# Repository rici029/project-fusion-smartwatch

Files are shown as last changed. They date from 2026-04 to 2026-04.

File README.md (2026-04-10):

# InkTime - Smartwatch Open Source

InkTime este un smartwatch ieftin, open-source, construit in jurul microcontroller-ului **Nordic nRF52840** (BLE 5 + ARM Cortex-M4) si a unui display **e-paper de 1.54"**. Consumul redus al e-paper-ului combinat cu eficienta nRF-ului permite o autonomie de cateva zile pe o baterie LiPo mica.

---

## Cuprins

- [Diagrama bloc](#diagrama-bloc)
- [Descriere hardware](#descriere-hardware)
- [Bill of Materials (BOM)](#bill-of-materials-bom)
- [Pin mapping nRF52840](#pin-mapping-nrf52840)
- [Estimare consum energie](#estimare-consum-energie)
- [Design mecanic](#design-mecanic)
- [Design log](#design-log)
- [Structura repository-ului](#structura-repository-ului)
- [Licenta](#licenta)

---

## Diagrama bloc

Arhitectura dispozitivului se bazeaza pe nRF52840 ca hub central. Acesta comunica cu:

- **Display e-paper** prin SPI + semnale de control (DC/RST/BUSY)
- **Accelerometrul BMA423** prin I2C (pentru detectarea miscarii si step counter)
- **PMIC BQ25180** prin I2C (management incarcare baterie Li-Ion)
- **Driver haptic DRV2605** prin I2C (feedback vibrator)
- **USB-C** pentru incarcare si comunicatie seriala (USB nativ al nRF)
- **3 butoane** pe GPIO-uri dedicate
- **Antena chip 2.4GHz** pentru BLE

Alimentarea este furnizata de un buck-boost **RT6160** care genereaza 3.3V stabil din baterie (domeniu tipic 3.0-4.2V).

---

## Descriere hardware

### Microcontroller - Nordic nRF52840

- **Core:** ARM Cortex-M4F @ 64 MHz
- **Memorie:** 1 MB Flash + 256 KB RAM
- **Radio:** BLE 5.3, 2.4 GHz, puterea TX pana la +8 dBm
- **Interfete:** USB 2.0 Full Speed nativ, SPI, I2C, UART, I2S, PDM, QSPI
- **Justificare alegere:** consum redus (~5 uA in System OFF cu RAM retinuta), suport BLE complet, USB nativ care elimina nevoia de USB-to-Serial

### Power Management

**BQ25180 - Battery Charger (IC1)**
- Incarcator Li-Ion de 1 celula, pana la 550 mA
- Protectii integrate: OVP, SCP, termica
- Control prin I2C - poate raporta starea bateriei si curentul de incarcare
- Pin ALERT (interrupt) catre nRF pentru notificare evenimente

**RT6160 - Buck-Boost DC/DC (IC2)**
- Intrare: 2.5-5.5V (acopera atat VBAT cat si VBUS de la USB)
- Iesire: 3.3V (VREG -> 3V3 rail intern)
- Eficienta >90% la sarcini tipice
- Iesirea VSEL configurabila digital

### Senzori

**BMA423 - Accelerometru 3-axe (IC3)**
- 16-bit, range +/-2/+/-4/+/-8/+/-16 g
- Consum ultra-low: ~3 uA in low-power mode
- Features integrate: step counter, wake-on-tilt, activity recognition
- Comunicatie: I2C
- Doua interrupt-uri (INT1, INT2) pentru wake-up asincron al nRF

### Haptic Feedback

**DRV2605 - Haptic Driver (IC4)**
- Driver pentru motor ERM/LRA (shaker coin motor)
- Librarie integrata de 123 efecte preset
- Control I2C + enable digital (HAPTIC_EN)

### Display

**E-paper 1.54" (model WSH-12561, 200x200 pixel)**
- Conectat prin SPI (MOSI, SCK, EPD_CS) + 3 semnale control (DC, RST, BUSY)
- Circuit de boost integrat - foloseste componentele externe EPD_C1..EPD_C12 (condensatoare + inductor L2, L3 + diode D1-D3 pentru generarea PREVGL/PREVGH/GDR)
- Activare alimentare 3.3V prin MOSFET Q2 controlat de EPD_CS

### USB si protectie

**Conector USB-C (J3)** cu 16 pini (reversibil)
**USBLC6-2SC6Y (D4)** - ESD protection pe liniile D+/D-
Conectare directa la nRF52840 (USB nativ integrat)

### Circuit RF

Antena **2450AT18B100E** (Johanson) cu pi-network de matching:
- **C13, C15, C16** - condensatoare de acord
- **L4 (3.9 nH)** - inductor de matching
- **X1 (32 MHz)** - cristal pentru PLL radio, cu condensatoare de sarcina (12pF)
- **X2 (32.768 kHz)** - cristal pentru RTC (wake-up periodic low-power)

---

## Bill of Materials (BOM)

| Ref | Componenta | Valoare / Model | Capsula | Link JLC Parts | Datasheet |
|-----|---|---|---|---|---|
| IC - nRF | Microcontroller | nRF52840-QIAA | aQFN73 | [JLC](https://jlcpcb.com/parts) | [PDF](https://infocenter.nordicsemi.com/pdf/nRF52840_PS_v1.7.pdf) |
| IC1 | Battery Charger PMIC | BQ25180 | WCSP-8 | [JLC](https://jlcpcb.com/parts) | [PDF](https://www.ti.com/lit/ds/symlink/bq25180.pdf) |
| IC2 | Buck-Boost DC/DC | RT6160A | WQFN-15 | [JLC](https://jlcpcb.com/parts) | [PDF](https://www.richtek.com/assets/product_file/RT6160A/DS6160A-00.pdf) |
| IC3 | Accelerometer | BMA423 | LGA-12 | [JLC](https://jlcpcb.com/parts) | [PDF](https://www.bosch-sensortec.com/media/boschsensortec/downloads/datasheets/bst-bma423-ds000.pdf) |
| IC4 | Haptic Driver | DRV2605 | WCSP-9 | [JLC](https://jlcpcb.com/parts) | [PDF](https://www.ti.com/lit/ds/symlink/drv2605.pdf) |
| U1 | Fuel Gauge | (MAX17048 / LC709203) | WCSP-8 | [JLC](https://jlcpcb.com/parts) | [PDF](https://www.analog.com/media/en/technical-documentation/data-sheets/MAX17048-MAX17049.pdf) |
| ANT1 | Chip Antenna 2.4GHz | 2450AT18B100E | SMD | [JLC](https://jlcpcb.com/parts) | [PDF](https://www.johansontechnology.com/datasheets/2450AT18B100/2450AT18B100.pdf) |
| X1 | Cristal | 32 MHz | 3.2x2.5 mm | [JLC](https://jlcpcb.com/parts) | - |
| X2 | Cristal | 32.768 kHz | 3.2x1.5 mm | [JLC](https://jlcpcb.com/parts) | - |
| L1 | Inductor DC/DC | MLP2016 470nH | 2016 | [JLC](https://jlcpcb.com/parts) | - |
| L2 | Inductor E-paper | 10 uH | 0603 | [JLC](https://jlcpcb.com/parts) | - |
| L3 | Inductor E-paper | 15 uH | 0603 | [JLC](https://jlcpcb.com/parts) | - |
| L4 | Inductor RF matching | 3.9 nH | 0201 | [JLC](https://jlcpcb.com/parts) | - |
| Q2 | MOSFET P-channel | (EPD power switch) | SOT-23 | [JLC](https://jlcpcb.com/parts) | - |
| D1-D3 | Dioda Schottky | (boost converter) | SOD-323 | [JLC](https://jlcpcb.com/parts) | - |
| D4 | ESD USB Protection | USBLC6-2SC6Y | SOT-23-6 | [JLC](https://jlcpcb.com/parts) | [PDF](https://www.st.com/resource/en/datasheet/usblc6-2.pdf) |
| J1 | SWD Programming | TC2030-IDC | THT | [JLC](https://jlcpcb.com/parts) | [PDF](https://www.tag-connect.com/wp-content/uploads/bsk-pdf-manager/TC2030-IDC_Datasheet_14.pdf) |
| J2 | FPC Connector | 503480-2400 (24p) | SMD | [JLC](https://jlcpcb.com/parts) | [PDF](https://www.molex.com/pdm_docs/sd/5034802400_sd.pdf) |
| J3 | USB-C | KH-TYPE-C-16P | SMD | [JLC](https://jlcpcb.com/parts) | - |
| SW1-3 | Buton tactil | SMD side-push | SMD | [JLC](https://jlcpcb.com/parts) | - |
| Baterie | LiPo 3.7V | AKY0106 | - | - | [PDF](https://www.tme.eu/Document/b9e12bf26ad0ba929a22ab5d58f022cd/AKY0106.pdf) |
| Display | E-paper 1.54" | WSH-12561 | FPC | - | [PDF](https://www.tme.eu/Document/0ca57a8ffbcd57b5bca53252eb9d6ec3/WSH-12561.pdf) |
| Shaker | Motor vibrator | DFRobot FIT0774 | coin | - | [link](https://www.tme.eu/ro/details/df-fit0774/motoare-dc/dfrobot/fit0774/) |

**Condensatoare si rezistente:** toate in capsule 0201 (pentru valori <= 100 nF) sau 0402 (pentru valori > 100 nF), conform cerintei proiectului. Vezi fisierul `Manufacturing/bom.txt` pentru lista completa cu referinte si valori.

---

## Pin mapping nRF52840

| Pin nRF52840 | Net / Semnal | Functie | Motivatie alegere |
|---|---|---|---|
| P0.26 | SCL | I2C Clock | Pin GPIO standard, aproape de IC-urile I2C (BMA423, BQ25180, DRV2605) pentru trase scurte |
| P0.27 | SDA | I2C Data | Pereche cu P0.26 pentru TWI0 |
| P0.04 | IMU_INT1 | Interrupt BMA423 | Pin cu capabilitate AIN (ADC) dar folosit ca GPIO - pozitie convenabila pe PCB |
| P0.13 | SCK | SPI Clock (E-paper) | High-speed GPIO, suport SPIM |
| P0.14 | MOSI | SPI Data (E-paper) | Pereche cu SCK pe aceeasi periferica SPIM |
| P0.19 | EPD_CS | Chip Select e-paper | GPIO simplu, control SPI CS |
| P0.20 | EPD_DC | Data/Command | Control semnal pentru display |
| P0.21 | EPD_RST | Reset e-paper | GPIO cu output drive standard |
| P0.22 | EPD_BUSY | Busy signal | Input de la display, pentru polling |
| P0.23 | HAPTIC_EN | Enable DRV2605 | GPIO simplu, activeaza driver-ul haptic |
| P0.24 | PMIC_INT | Interrupt BQ25180 | Interrupt la evenimente de charging |
| P0.25 | ALERT | Alert fuel gauge | Notificare low-battery |
| P0.09, P0.10 | SW1, SW2 (Buttons) | Butoane utilizator | Pini dedicati cu suport NFC dezactivat (configurabili GPIO) |
| P1.09 | SW3 | Al treilea buton | GPIO free pe portul P1 |
| P1.01 | IMU_INT2 | Interrupt secundar BMA423 | GPIO free |
| SWDIO, SWDCLK | TP + J1 | Programming / Debug | Pini dedicati SWD, accesibili prin TC2030 si test pad-uri |
| XL1, XL2 | X2 (32.768 kHz) | LFCLK pentru RTC | Pini dedicati oscilatorului low-frequency |
| XC1, XC2 | X1 (32 MHz) | HFCLK pentru radio | Pini dedicati oscilatorului high-frequency |
| D+/D- | USB | USB native | Pini dedicati, conectati direct la USB-C prin USBLC6 |
| ANT | ANT1 | Antena BLE | Pin RF dedicat, conectat prin reteaua de matching |

**Nota:** Pinii ADC (P0.02-P0.05, P0.28-P0.31) care nu sunt folositi ca AIN sunt disponibili pentru extensii viitoare (ex: senzori analogici aditionali).

---

## Estimare consum energie

| Mod de operare | Componente active | Consum estimat |
|---|---|---|
| Sleep (System OFF + RAM) | nRF RAM retained + RTC + BMA423 low-power | **~10 uA** |
| Idle (display static, BLE advertising) | nRF BLE adv + RTC + IMU | **~50 uA** |
| Active (refresh display) | nRF MCU on + SPI + EPD boost | ~8 mA (~500 ms per refresh) |
| BLE connected (data transfer) | nRF radio TX/RX @ 0 dBm | ~5-8 mA |
| Charging | BQ25180 la 500 mA | de la USB, nu de la baterie |

**Autonomie estimata:**  
Baterie tipica: ~110 mAh (AKY0106).  
Cu consum mediu ~50 uA (majoritatea timpului in idle + cateva refresh-uri de display pe ora):

T_autonomie = 110 mAh / 0.05 mA = 2200 ore ~ 90 zile

In practica, cu uzura normala (notificari, interactiuni cu butoanele, sync BLE), **durata de viata realista pe baterie este de ~2-4 saptamani**.

---

## Design mecanic

Dispozitivul este construit din:
- **PCB 1 mm grosime**, 4 layere (Top + 2 Inner GND + Bottom)
- **Carcasa** cu TopCase (rama + fereastra display) + BottomCase (compartiment baterie)
- **Baterie LiPo** plasata sub PCB in compartimentul BottomCase
- **Display e-paper** montat deasupra PCB, aliniat cu fereastra TopCase
- **Shaker motor** plasat lateral, conectat la PCB prin pad-uri TP_OUT+/OUT-
- **3 butoane fizice** aliniate cu SW1-SW3 pe PCB

Bateria se conecteaza direct la 2 test pad-uri (TP_BAT / TP_GND) in loc sa foloseasca conectorul JST original, pentru a economisi spatiu.

---

## Design log

### Decizii importante luate

1. **Alegerea stack-up-ului 4 layere:** desi un design 2-layer ar fi fost posibil, am optat pentru 4 layere cu doua planuri GND interne (Optiunea B). Motivele:
   - Return path continuu pentru semnalele SPI (display) si USB D+/D-
   - Performanta RF mai buna pentru circuitul BLE 2.4 GHz
   - Simplificare rutare - nu mai trebuie evitate via-urile pe trasee de putere
   - Ecranare EMI imbunatatita intre TOP si BOTTOM

2. **Rutarea 3V3 ca trasee groase (nu plane):** pentru ca 3V3 e consumator redus (< 100 mA) am preferat trasee groase (0.3 mm) pe TOP/BOTTOM in loc de un plane intern. Inner layers raman ambele GND.

3. **Antena la marginea PCB-ului + decupare:** am plasat antena 2450AT18B100E la marginea placii, cu zona de sub ea **decupata mecanic** si fara cupru pe niciun layer (conform datasheet si cerintei). In jurul antenei am adaugat via stitching pentru a lega planurile GND.

4. **Keepout pe toate cele 4 layere sub antena:** am desenat dreptunghiuri pe tRestrict, bRestrict si echivalentele pentru inner layers, plus decupare pe Dimension/Milling.

5. **Via stitching in zona RF:** plasate via-uri GND (0.3 mm drill / 0.6 mm diametru) la ~1.5 mm distanta in jurul nRF52840 si antenei pentru continuitate planuri GND.

6. **Plasarea condensatoarelor de decuplare:** toate cele 100 nF sunt plasate in capsula 0201 direct langa pinii VDD ai nRF, BMA423, DRV2605, BQ25180 si RT6160.

### Probleme intampinate

- **Rutare sub BGA nRF52840:** pinii interni ai BGA-ului au spatiere foarte mica; traseele de intrare/iesire din zona BGA au fost ingustate la 0.127 mm pentru a se incadra intre bile. Au aparut erori DRC "width too small" dar sunt acceptate conform cerintei.
- **Spatiu limitat pentru rutare:** placa de smartwatch fiind compacta (~35x40 mm), am trecut la 4 layere pentru a avea suficient spatiu de rutare.
- **Orientarea FPC-ului display-ului:** conectorul J2 a fost orientat astfel incat cablul flat sa aiba lungime minima pana la display, fara bucle.
- **Net classes aplicate dupa ce am inceput rutarea:** am adaugat clasa "Power" cu width 0.3 mm dupa ce rutasem deja cateva trasee la 0.15 mm. Am folosit comanda CHANGE WIDTH pentru a le ingrosa.

---

## Structura repository-ului

```
InkTime/
├── Hardware/
│   ├── InkTime_Schematic.sch     # Schematicul Fusion
│   ├── InkTime_Schematic.brd     # Board-ul Fusion
│   └── InkTime_Schematic.pdf     # Print-out schematic
├── Manufacturing/
│   ├── gerbers.zip               # Fisiere Gerber + Drill
│   ├── bom.txt                   # Bill of Materials
│   └── cpl.txt                   # Pick and Place
├── Mechanical/
│   ├── complete_device.step      # Model 3D exploded
│   └── complete_device.f3z       # Fisier Fusion Design complet
├── Images/
│   ├── block_diagram.png
│   ├── pcb_top.png
│   ├── pcb_bottom.png
│   ├── pcb_3d_top.png
│   └── device_3d.png
├── LICENSE                       # Apache 2.0
└── README.md
```

---

## Licenta

Acest proiect este licentiat sub **Apache License 2.0**. Vezi fisierul [LICENSE](LICENSE) pentru detalii.

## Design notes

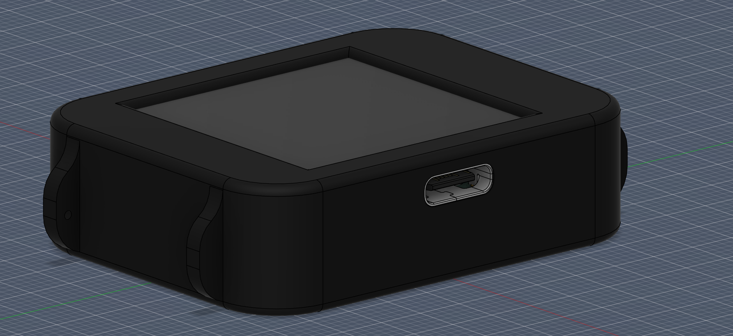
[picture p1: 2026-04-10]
device_3d.png

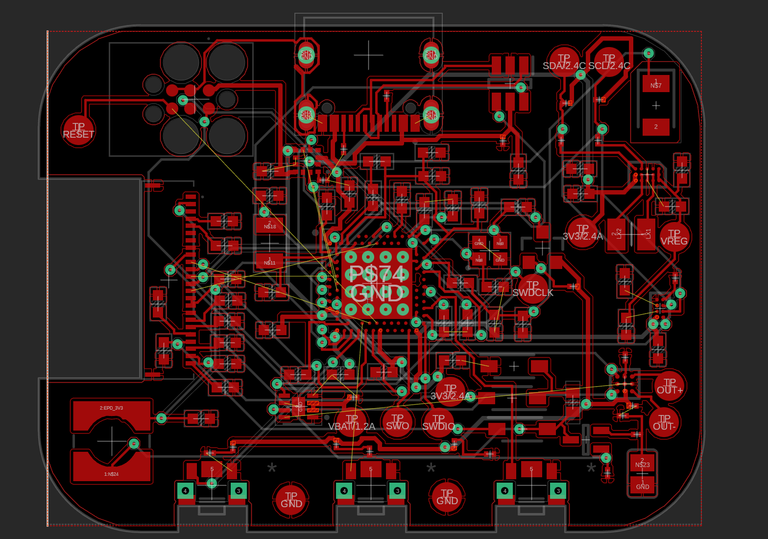
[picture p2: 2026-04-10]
pcb_top.png

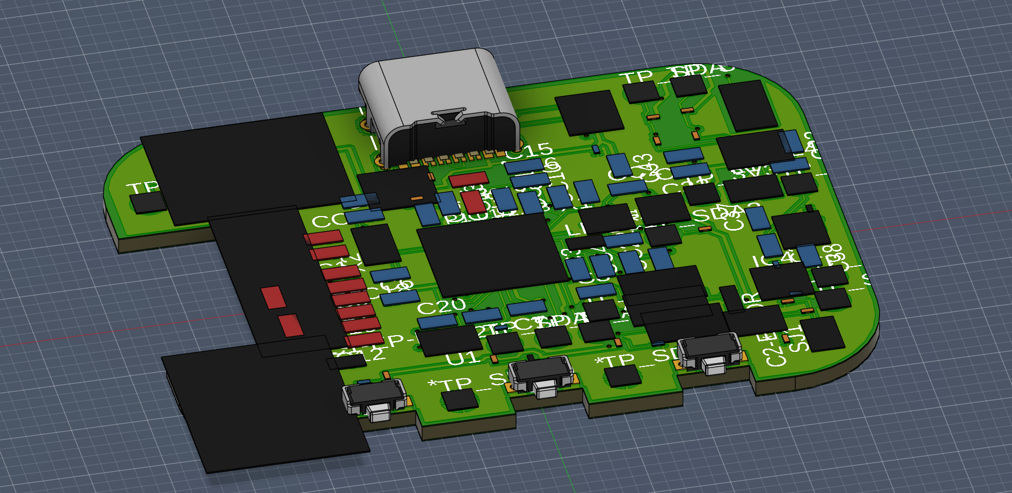
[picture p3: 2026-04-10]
pcb_3d.png

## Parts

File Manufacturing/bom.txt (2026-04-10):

Partlist exported from Fusion Hub: bogdanpanaitiu   Project: Default Project  Board: InkTime_Schematic at 19/04/2026 16:12

Qty Value                                                   Device                                                                       Package                                                                                                                Parts                                                                                                                      Description                                                                                                               ARROW_PART_NUMBER ARROW_PRICE-STOCK                                                                                AVAILABILITY CHECK_PRICES                                                                       COPYRIGHT                                                DESCRIPTION                                                                                              DIGI-KEY_PART_NUMBER_1                    DIGI-KEY_PART_NUMBER_2 DIGI-KEY_PART_NUMBER_3                              HEIGHT  JLCPCB MANUFACTURER_NAME   MANUFACTURER_PART_NUMBER                                         MF                 MFR_NAME          MOUSER_PART_NUMBER MOUSER_PRICE-STOCK                                                                                           MP                                                                                                       PACKAGE                     POPULARITY PRICE            PROD_ID                      PURCHASE-URL                                                                                                                               SNAPEDA_LINK                                                                      SPICEMODEL SPICEPREFIX                                                                                                                                     TP_SIGNAL_NAME                                                                      VALUE             
1   0                                                       ESP32_C6_LIBRARY_7_JUMPER_SJ                                                 ESP32_C6_LIBRARY_7_JUMPER_SJ                                                                                           SJ1                                                                                                                        SMD solder JUMPER                                                                                                                                                                                                                                                                                                                                                                                                                                                                                                                                                                                                                                                                                                                                                                                                                                                                                                                                                                                                                                 3                                                                                                                                                                                                                                                                                                                                                                                                                                                                                                                                                      
1   0.1uF                                                   GRM011R60J152KE01L_1_GRM011R60J152KE01L                                      GRM011R60J152KE01L_1_0201                                                                                              C4                                                                                                                         Check availability                                                                                                                                                                                                                                                                                                                                                                                                                                                                                                                                                                                                                                                                                                                                                                                                                                                                                                                                                                                                                                                                                                                                                                                                                                                                                                                                                                                                                                                                                                                                                                                       
1   0.1uF                                                   NORDIC_NRF_3_CAPACITOR_0402_M                                                NORDIC_NRF_3_RESC0402_M                                                                                                C23                                                                                                                        Generic chip capacitor                                                                                                                                                                                                                                                                                                                                                                                                                                                                                                                                                                                                                                                                                                                                                                                                                                                                                                                                                                                                                                                                                                                                                                                                                                                                                                                                                                                                                                                                                                                                                                                   
1   0.1uF/50V                                               NORDIC_NRF_3_CAPACITOR_0402_M                                                NORDIC_NRF_3_RESC0402_M                                                                                                EPD_C5                                                                                                                     Generic chip capacitor                                                                                                                                                                                                                                                                                                                                                                                                                                                                                                                                                                                                                                                                                                                                                                                                                                                                                                                                                                                                                                                                                                                                                                                                                                                                                                                                                                                                                                                                                                                                                                                   
4   100nF                                                   NORDIC_NRF_3_CAPACITOR_0402_M                                                NORDIC_NRF_3_RESC0402_M                                                                                                C7, C8, CC5, CC19                                                                                                          Generic chip capacitor                                                                                                                                                                                                                                                                                                                                                                                                                                                                                                                                                                                                                                                                                                                                                                                                                                                                                                                                                                                                                                                                                                                                                                                                                                                                                                                                                                                                                                                                                                                                                                                   
2   100pF                                                   NORDIC_NRF_3_CAPACITOR_0402_M                                                NORDIC_NRF_3_RESC0402_M                                                                                                C12, CC11                                                                                                                  Generic chip capacitor                                                                                                                                                                                                                                                                                                                                                                                                                                                                                                                                                                                                                                                                                                                                                                                                                                                                                                                                                                                                                                                                                                                                                                                                                                                                                                                                                                                                                                                                                                                                                                                   
1   10K                                                     CPF0201D7K68C1_CPF0201D7K68C1                                                CPF0201D7K68C1_0201                                                                                                    R1                                                                                                                         7.68k 0201 Thin Film Surface Mount Fixed Resistor +/-0.5% 0.031W CPF0201D7K68C1                                                                                                                                                                                                                                                                                                                                                                                                                                                                                                                                                                                                                                                                                                                                                                                                                                                                                                                                                                                                                                                                                                                                                                                                                                                                                                                                                                                                                                                                                                                          
3   10uF                                                    NORDIC_NRF_3_CAPACITOR_0402_M                                                NORDIC_NRF_3_RESC0402_M                                                                                                C1-EP-DR, C24, C39                                                                                                         Generic chip capacitor                                                                                                                                                                                                                                                                                                                                                                                                                                                                                                                                                                                                                                                                                                                                                                                                                                                                                                                                                                                                                                                                                                                                                                                                                                                                                                                                                                                                                                                                                                                                                                                   
1   10uH                                                    NORDIC_NRF_2_INDUCTOR_0402_M                                                 NORDIC_NRF_2_RESC0402_M                                                                                                LL2                                                                                                                        Generic chip inductor                                                                                                                                                                                                                                                                                                                                                                                                                                                                                                                                                                                                                                                                                                                                                                                                                                                                                                                                                                                                                                                                                                                                                                                                                                                                                                                                                                                                                                                                                                                                                                                    
4   12pF                                                    NORDIC_NRF_3_CAPACITOR_0402_M                                                NORDIC_NRF_3_RESC0402_M                                                                                                C17, C18, CC1, CC2                                                                                                         Generic chip capacitor                                                                                                                                                                                                                                                                                                                                                                                                                                                                                                                                                                                                                                                                                                                                                                                                                                                                                                                                                                                                                                                                                                                                                                                                                                                                                                                                                                                                                                                                                                                                                                                   
1   15uH                                                    NORDIC_NRF_2_INDUCTOR_0402_M                                                 NORDIC_NRF_2_RESC0402_M                                                                                                LL3                                                                                                                        Generic chip inductor                                                                                                                                                                                                                                                                                                                                                                                                                                                                                                                                                                                                                                                                                                                                                                                                                                                                                                                                                                                                                                                                                                                                                                                                                                                                                                                                                                                                                                                                                                                                                                                    
2   1pF                                                     NORDIC_NRF_3_CAPACITOR_0402_M                                                NORDIC_NRF_3_RESC0402_M                                                                                                CC3, CC4                                                                                                                   Generic chip capacitor                                                                                                                                                                                                                                                                                                                                                                                                                                                                                                                                                                                                                                                                                                                                                                                                                                                                                                                                                                                                                                                                                                                                                                                                                                                                                                                                                                                                                                                                                                                                                                                   
1   1uF                                                     GRM011R60J152KE01L_1_GRM011R60J152KE01L                                      GRM011R60J152KE01L_1_0201                                                                                              C3                                                                                                                         Check availability                                                                                                                                                                                                                                                                                                                                                                                                                                                                                                                                                                                                                                                                                                                                                                                                                                                                                                                                                                                                                                                                                                                                                                                                                                                                                                                                                                                                                                                                                                                                                                                       
3   1uF                                                     NORDIC_NRF_3_CAPACITOR_0402_M                                                NORDIC_NRF_3_RESC0402_M                                                                                                C15, C37, C38                                                                                                              Generic chip capacitor
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

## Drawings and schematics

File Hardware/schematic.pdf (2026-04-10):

A

A

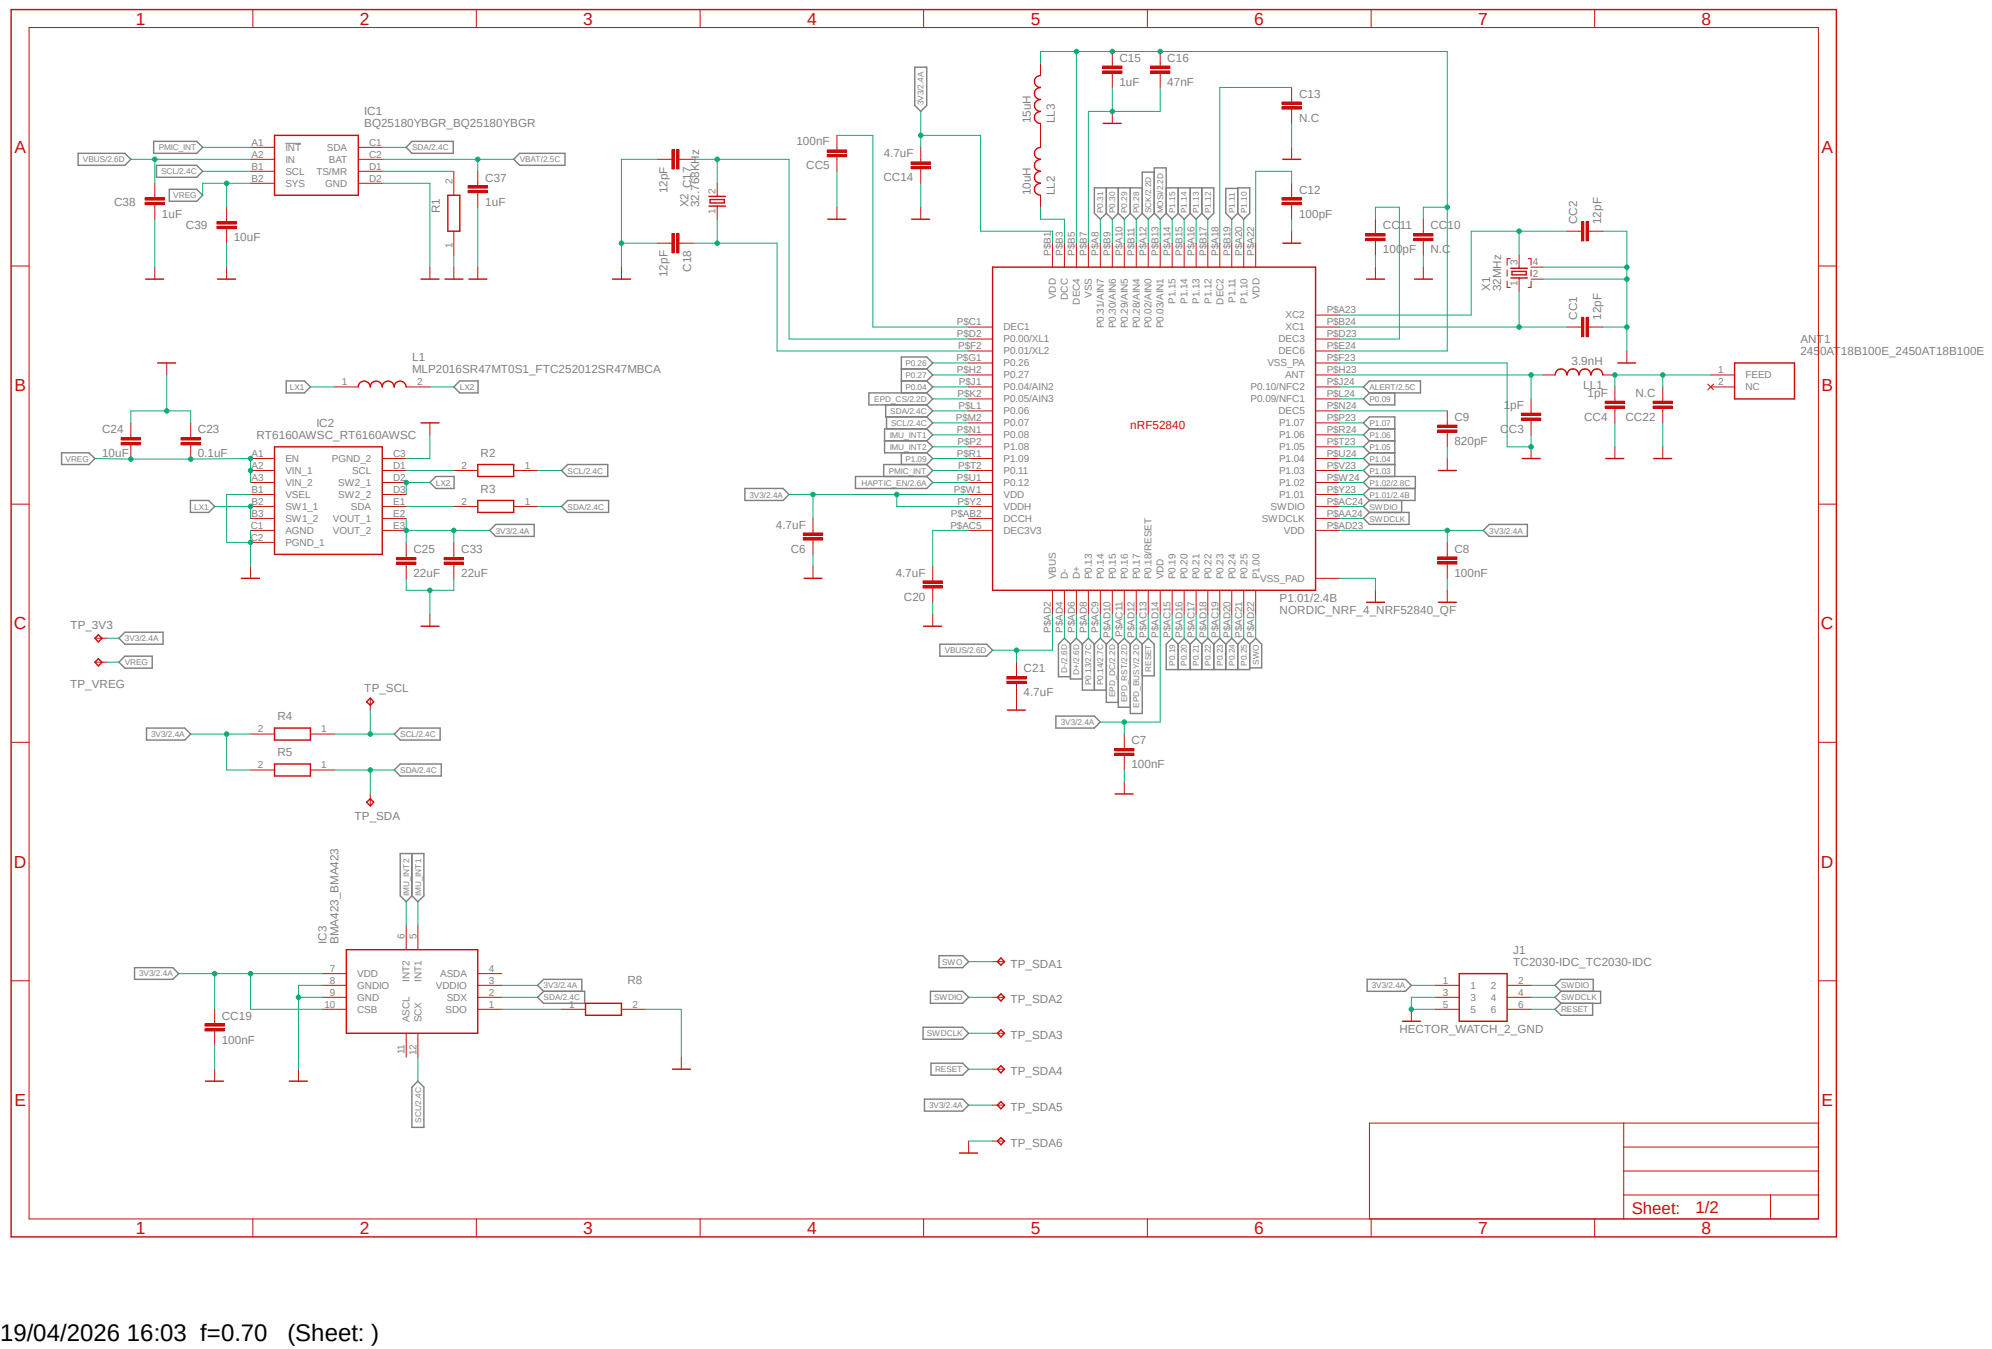
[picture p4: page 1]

P0.07 P$M2 | P1.07
P0.08 P$N1 | P1.06
P1.08 P$P2 | P1.05

19/04/2026 16:03 f=0.70 (Sheet: ) EPD_3V³ | EPD_3V³

# EPD_3V3 GDR

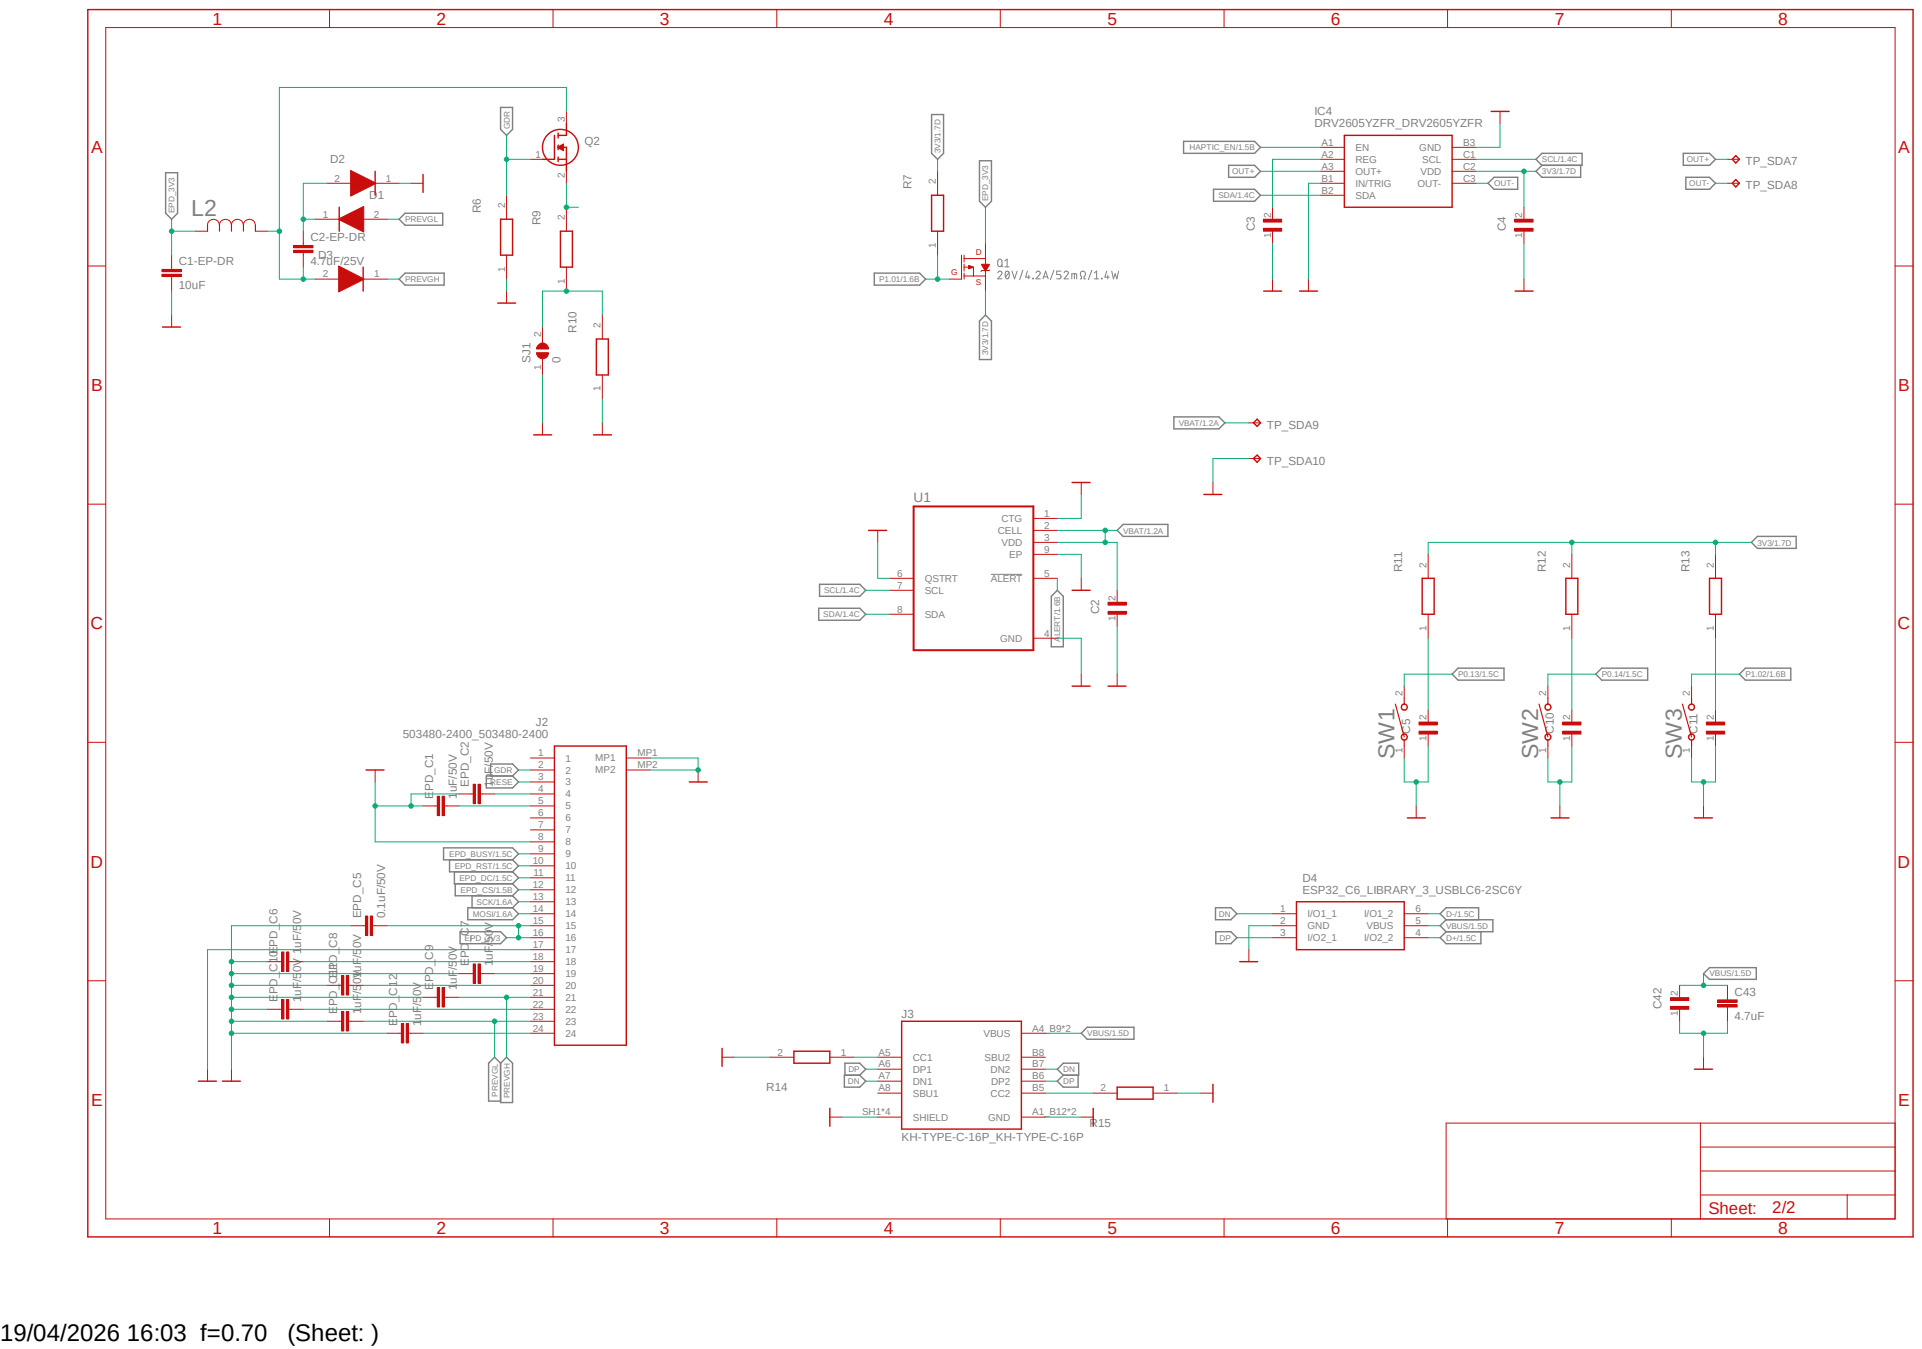
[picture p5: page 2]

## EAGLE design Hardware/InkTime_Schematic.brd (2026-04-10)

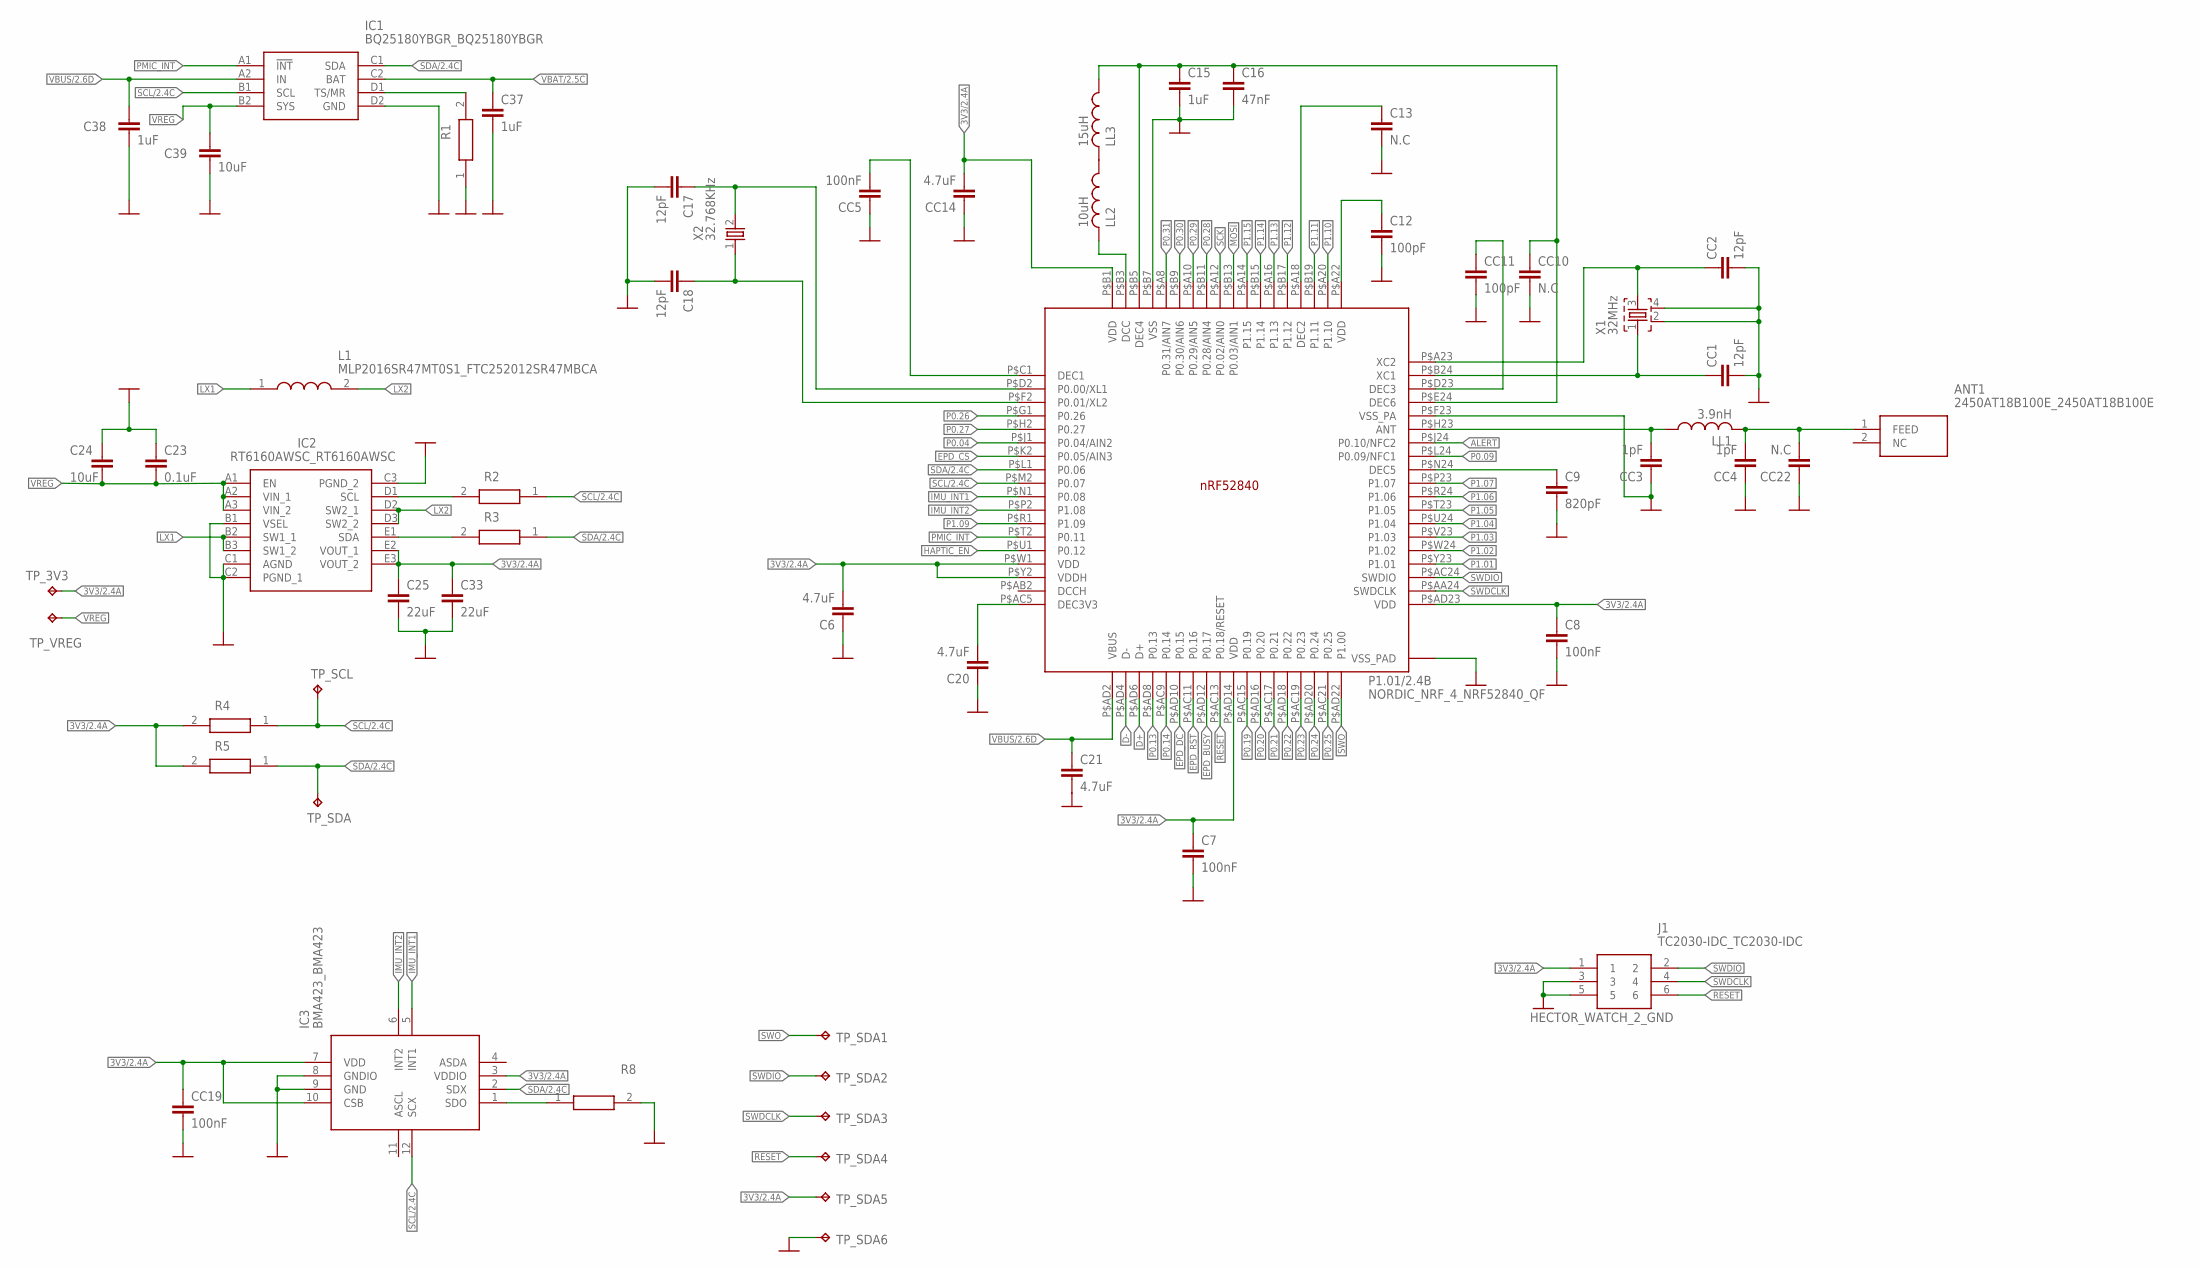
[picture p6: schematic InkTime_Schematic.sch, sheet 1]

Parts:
ANT1: 2450AT18B100E_2450AT18B100E; 2450AT18B100E_ANTC3216X140N
C6, C20, C21: 4.7uF; NORDIC_NRF_3_RESC0402_M
C7, C8: 100nF; NORDIC_NRF_3_RESC0402_M
C9: 820pF; NORDIC_NRF_3_RESC0402_M
C12: 100pF; NORDIC_NRF_3_RESC0402_M
C13: N.C; NORDIC_NRF_3_RESC0402_M
C15, C37, C38: 1uF; NORDIC_NRF_3_RESC0402_M
C16: 47nF; NORDIC_NRF_3_RESC0402_M
C17, C18: 12pF; NORDIC_NRF_3_RESC0402_M
C23: 0.1uF; NORDIC_NRF_3_RESC0402_M
C24, C39: 10uF; NORDIC_NRF_3_RESC0402_M
C25, C33: 22uF; NORDIC_NRF_3_RESC0402_M
CC1, CC2: 12pF; NORDIC_NRF_3_RESC0402_M
CC3, CC4: 1pF; NORDIC_NRF_3_RESC0402_M
CC5, CC19: 100nF; NORDIC_NRF_3_RESC0402_M
CC10, CC22: N.C; NORDIC_NRF_3_RESC0402_M
CC11: 100pF; NORDIC_NRF_3_RESC0402_M
CC14: 4.7uF; NORDIC_NRF_3_RESC0402_M
IC1: BQ25180YBGR_BQ25180YBGR; BQ25180YBGR_BGA8C40P2X4_100X155X50
IC2: RT6160AWSC_RT6160AWSC; RT6160AWSC_BGA15C40P3X5_140X230X60
IC3: BMA423_BMA423
J1: TC2030-IDC_TC2030-IDC; TC2030-IDC_TC2030IDC
L1: MLP2016SR47MT0S1_FTC252012SR47MBCA; MLP2016SR47MT0S1_INDC2016X100N
LL1: 3.9nH; NORDIC_NRF_2_RESC0402_M
LL2: 10uH; NORDIC_NRF_2_RESC0402_M
LL3: 15uH; NORDIC_NRF_2_RESC0402_M
P1.01/2.4B: NORDIC_NRF_4_NRF52840_QF; NORDIC_NRF_4_AQFN50P700X700X85_HS-74N
R1: 10K; CPF0201D7K68C1_0201
R2, R3, R4, R5, R8: CPF0201D7K68C1_CPF0201D7K68C1; CPF0201D7K68C1_0201
TP_3V3: HECTOR_WATCH_1_TPTP20R; HECTOR_WATCH_1_TP20R
TP_SCL: HECTOR_WATCH_1_TPTP20R; HECTOR_WATCH_1_TP20R
TP_SDA, TP_SDA1, TP_SDA2, TP_SDA3, TP_SDA4, TP_SDA5, TP_SDA6: HECTOR_WATCH_1_TPTP20R; HECTOR_WATCH_1_TP20R
TP_VREG: HECTOR_WATCH_1_TPTP20R; HECTOR_WATCH_1_TP20R
X1: 32MHz; NORDIC_NRF_BT-XTAL_2016_N
X2: 32.768KHz; NORDIC_NRF_1_XTAL_3215_N

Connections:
3V3/2.4A: C6.2, C7.1, C8.1, C25.1, C33.1, CC14.2, CC19.1, IC2.E2 (VOUT_1), IC2.E3 (VOUT_2), IC3.3 (VDDIO), IC3.7 (VDD), IC3.10 (CSB), J1.1, P1.01/2.4B.P$AD14 (VDD), P1.01/2.4B.P$AD23 (VDD), P1.01/2.4B.P$B1 (VDD), P1.01/2.4B.P$W1 (VDD), P1.01/2.4B.P$Y2 (VDDH), R4.2, R5.2, TP_3V3.TP, TP_SDA5.TP
ALERT: P1.01/2.4B.P$J24 (P0.10/NFC2); also elsewhere on the board
D+: P1.01/2.4B.P$AD6 (D+); also elsewhere on the board
D-: P1.01/2.4B.P$AD4 (D-); also elsewhere on the board
EPD_BUSY: P1.01/2.4B.P$AD12 (P0.17); also elsewhere on the board
EPD_CS: P1.01/2.4B.P$K2 (P0.05/AIN3); also elsewhere on the board
EPD_DC: P1.01/2.4B.P$AD10 (P0.15); also elsewhere on the board
EPD_RST: P1.01/2.4B.P$AC11 (P0.16); also elsewhere on the board
GND: C6.1, C7.2, C8.2, C9.2, C12.2, C13.2, C15.2, C16.2, C17.2, C18.2, C20.1, C21.2, C23.1, C24.1, C25.2, C33.2, C37.2, C38.2, C39.2, CC1.2, CC2.2, CC3.1, CC4.1, CC5.1, CC10.2, CC11.2, CC14.1, CC19.2, CC22.1, IC1.D2 (GND), IC2.B1 (VSEL), IC2.C1 (AGND), IC2.C2 (PGND_1), IC2.C3 (PGND_2), IC3.8 (GNDIO), IC3.9 (GND), J1.3, J1.5, P1.01/2.4B.P$74 (VSS_PAD), P1.01/2.4B.P$75 (VSS_PAD), P1.01/2.4B.P$76 (VSS_PAD), P1.01/2.4B.P$77 (VSS_PAD), P1.01/2.4B.P$78 (VSS_PAD), P1.01/2.4B.P$79 (VSS_PAD), P1.01/2.4B.P$80 (VSS_PAD), P1.01/2.4B.P$81 (VSS_PAD), P1.01/2.4B.P$82 (VSS_PAD), P1.01/2.4B.P$83 (VSS_PAD), P1.01/2.4B.P$84 (VSS_PAD), P1.01/2.4B.P$85 (VSS_PAD), P1.01/2.4B.P$86 (VSS_PAD), P1.01/2.4B.P$87 (VSS_PAD), P1.01/2.4B.P$88 (VSS_PAD), P1.01/2.4B.P$89 (VSS_PAD), P1.01/2.4B.P$90 (VSS_PAD), P1.01/2.4B.P$B7 (VSS), P1.01/2.4B.P$F23 (VSS_PA), R1.1, R8.2, TP_SDA6.TP, X1.2, X1.4; also elsewhere on the board
HAPTIC_EN: P1.01/2.4B.P$U1 (P0.12); also elsewhere on the board
IMU_INT1: IC3.5 (INT1), P1.01/2.4B.P$N1 (P0.08)
IMU_INT2: IC3.6 (INT2), P1.01/2.4B.P$P2 (P1.08)
LX1: IC2.B2 (SW1_1), IC2.B3 (SW1_2), L1.1
LX2: IC2.D2 (SW2_1), IC2.D3 (SW2_2), L1.2
MOSI: P1.01/2.4B.P$B13 (P0.03/AIN1); also elsewhere on the board
unnamed: IC1.D1 (TS/MR), R1.2
unnamed: C9.1, P1.01/2.4B.P$N24 (DEC5)
unnamed: CC3.2, LL1.1, P1.01/2.4B.P$H23 (ANT)
unnamed: IC2.D1 (SCL), R2.2
unnamed: IC2.E1 (SDA), R3.2
unnamed: C20.2, P1.01/2.4B.P$AC5 (DEC3V3)
unnamed: ANT1.1 (FEED), CC4.2, CC22.2, LL1.2
unnamed: CC1.1, P1.01/2.4B.P$B24 (XC1), X1.1
unnamed: CC2.1, P1.01/2.4B.P$A23 (XC2), X1.3
unnamed: CC11.1, P1.01/2.4B.P$D23 (DEC3)
unnamed: C18.1, P1.01/2.4B.P$F2 (P0.01/XL2), X2.1
unnamed: C12.1, P1.01/2.4B.P$A22 (VDD)
unnamed: C13.1, P1.01/2.4B.P$A18 (DEC2)
unnamed: LL2.1, LL3.2
unnamed: LL2.2, P1.01/2.4B.P$B3 (DCC)
unnamed: C15.1, C16.1, CC10.1, LL3.1, P1.01/2.4B.P$B5 (DEC4), P1.01/2.4B.P$E24 (DEC6)
unnamed: C17.1, P1.01/2.4B.P$D2 (P0.00/XL1), X2.2
unnamed: IC3.1 (SDO), R8.1
unnamed: CC5.2, P1.01/2.4B.P$C1 (DEC1)
P0.04: P1.01/2.4B.P$J1 (P0.04/AIN2)
P0.09: P1.01/2.4B.P$L24 (P0.09/NFC1)
P0.13: P1.01/2.4B.P$AD8 (P0.13); also elsewhere on the board
P0.14: P1.01/2.4B.P$AC9 (P0.14); also elsewhere on the board
P0.19: P1.01/2.4B.P$AC15 (P0.19)
P0.20: P1.01/2.4B.P$AD16 (P0.20)
P0.21: P1.01/2.4B.P$AC17 (P0.21)
P0.22: P1.01/2.4B.P$AD18 (P0.22)
P0.23: P1.01/2.4B.P$AC19 (P0.23)
P0.24: P1.01/2.4B.P$AD20 (P0.24)
P0.25: P1.01/2.4B.P$AC21 (P0.25)
P0.26: P1.01/2.4B.P$G1 (P0.26)
P0.27: P1.01/2.4B.P$H2 (P0.27)
P0.28: P1.01/2.4B.P$B11 (P0.28/AIN4)
P0.29: P1.01/2.4B.P$A10 (P0.29/AIN5)
P0.30: P1.01/2.4B.P$B9 (P0.30/AIN6)
P0.31: P1.01/2.4B.P$A8 (P0.31/AIN7)
P1.01: P1.01/2.4B.P$Y23 (P1.01); also elsewhere on the board
P1.02: P1.01/2.4B.P$W24 (P1.02); also elsewhere on the board
P1.03: P1.01/2.4B.P$V23 (P1.03)
P1.04: P1.01/2.4B.P$U24 (P1.04)
P1.05: P1.01/2.4B.P$T23 (P1.05)
P1.06: P1.01/2.4B.P$R24 (P1.06)
P1.07: P1.01/2.4B.P$P23 (P1.07)
P1.09: P1.01/2.4B.P$R1 (P1.09)
P1.10: P1.01/2.4B.P$A20 (P1.10)
P1.11: P1.01/2.4B.P$B19 (P1.11)
P1.12: P1.01/2.4B.P$B17 (P1.12)
P1.13: P1.01/2.4B.P$A16 (P1.13)
P1.14: P1.01/2.4B.P$B15 (P1.14)
P1.15: P1.01/2.4B.P$A14 (P1.15)
PMIC_INT: IC1.A1 (!INT), P1.01/2.4B.P$T2 (P0.11)
RESET: J1.6, P1.01/2.4B.P$AC13 (P0.18/RESET), TP_SDA4.TP
SCK: P1.01/2.4B.P$A12 (P0.02/AIN0); also elsewhere on the board
SCL/2.4C: IC1.B1 (SCL), IC3.12 (SCX), P1.01/2.4B.P$M2 (P0.07), R2.1, R4.1, TP_SCL.TP
SDA/2.4C: IC1.C1 (SDA), IC3.2 (SDX), P1.01/2.4B.P$L1 (P0.06), R3.1, R5.1, TP_SDA.TP
SWDCLK: J1.4, P1.01/2.4B.P$AA24 (SWDCLK), TP_SDA3.TP
SWDIO: J1.2, P1.01/2.4B.P$AC24 (SWDIO), TP_SDA2.TP
SWO: P1.01/2.4B.P$AD22 (P1.00), TP_SDA1.TP
VBAT/2.5C: C37.1, IC1.C2 (BAT)
VBUS/2.6D: C21.1, C38.1, IC1.A2 (IN), P1.01/2.4B.P$AD2 (VBUS)
VREG: C23.2, C24.2, C39.1, IC1.B2 (SYS), IC2.A1 (EN), IC2.A2 (VIN_1), IC2.A3 (VIN_2), TP_VREG.TP

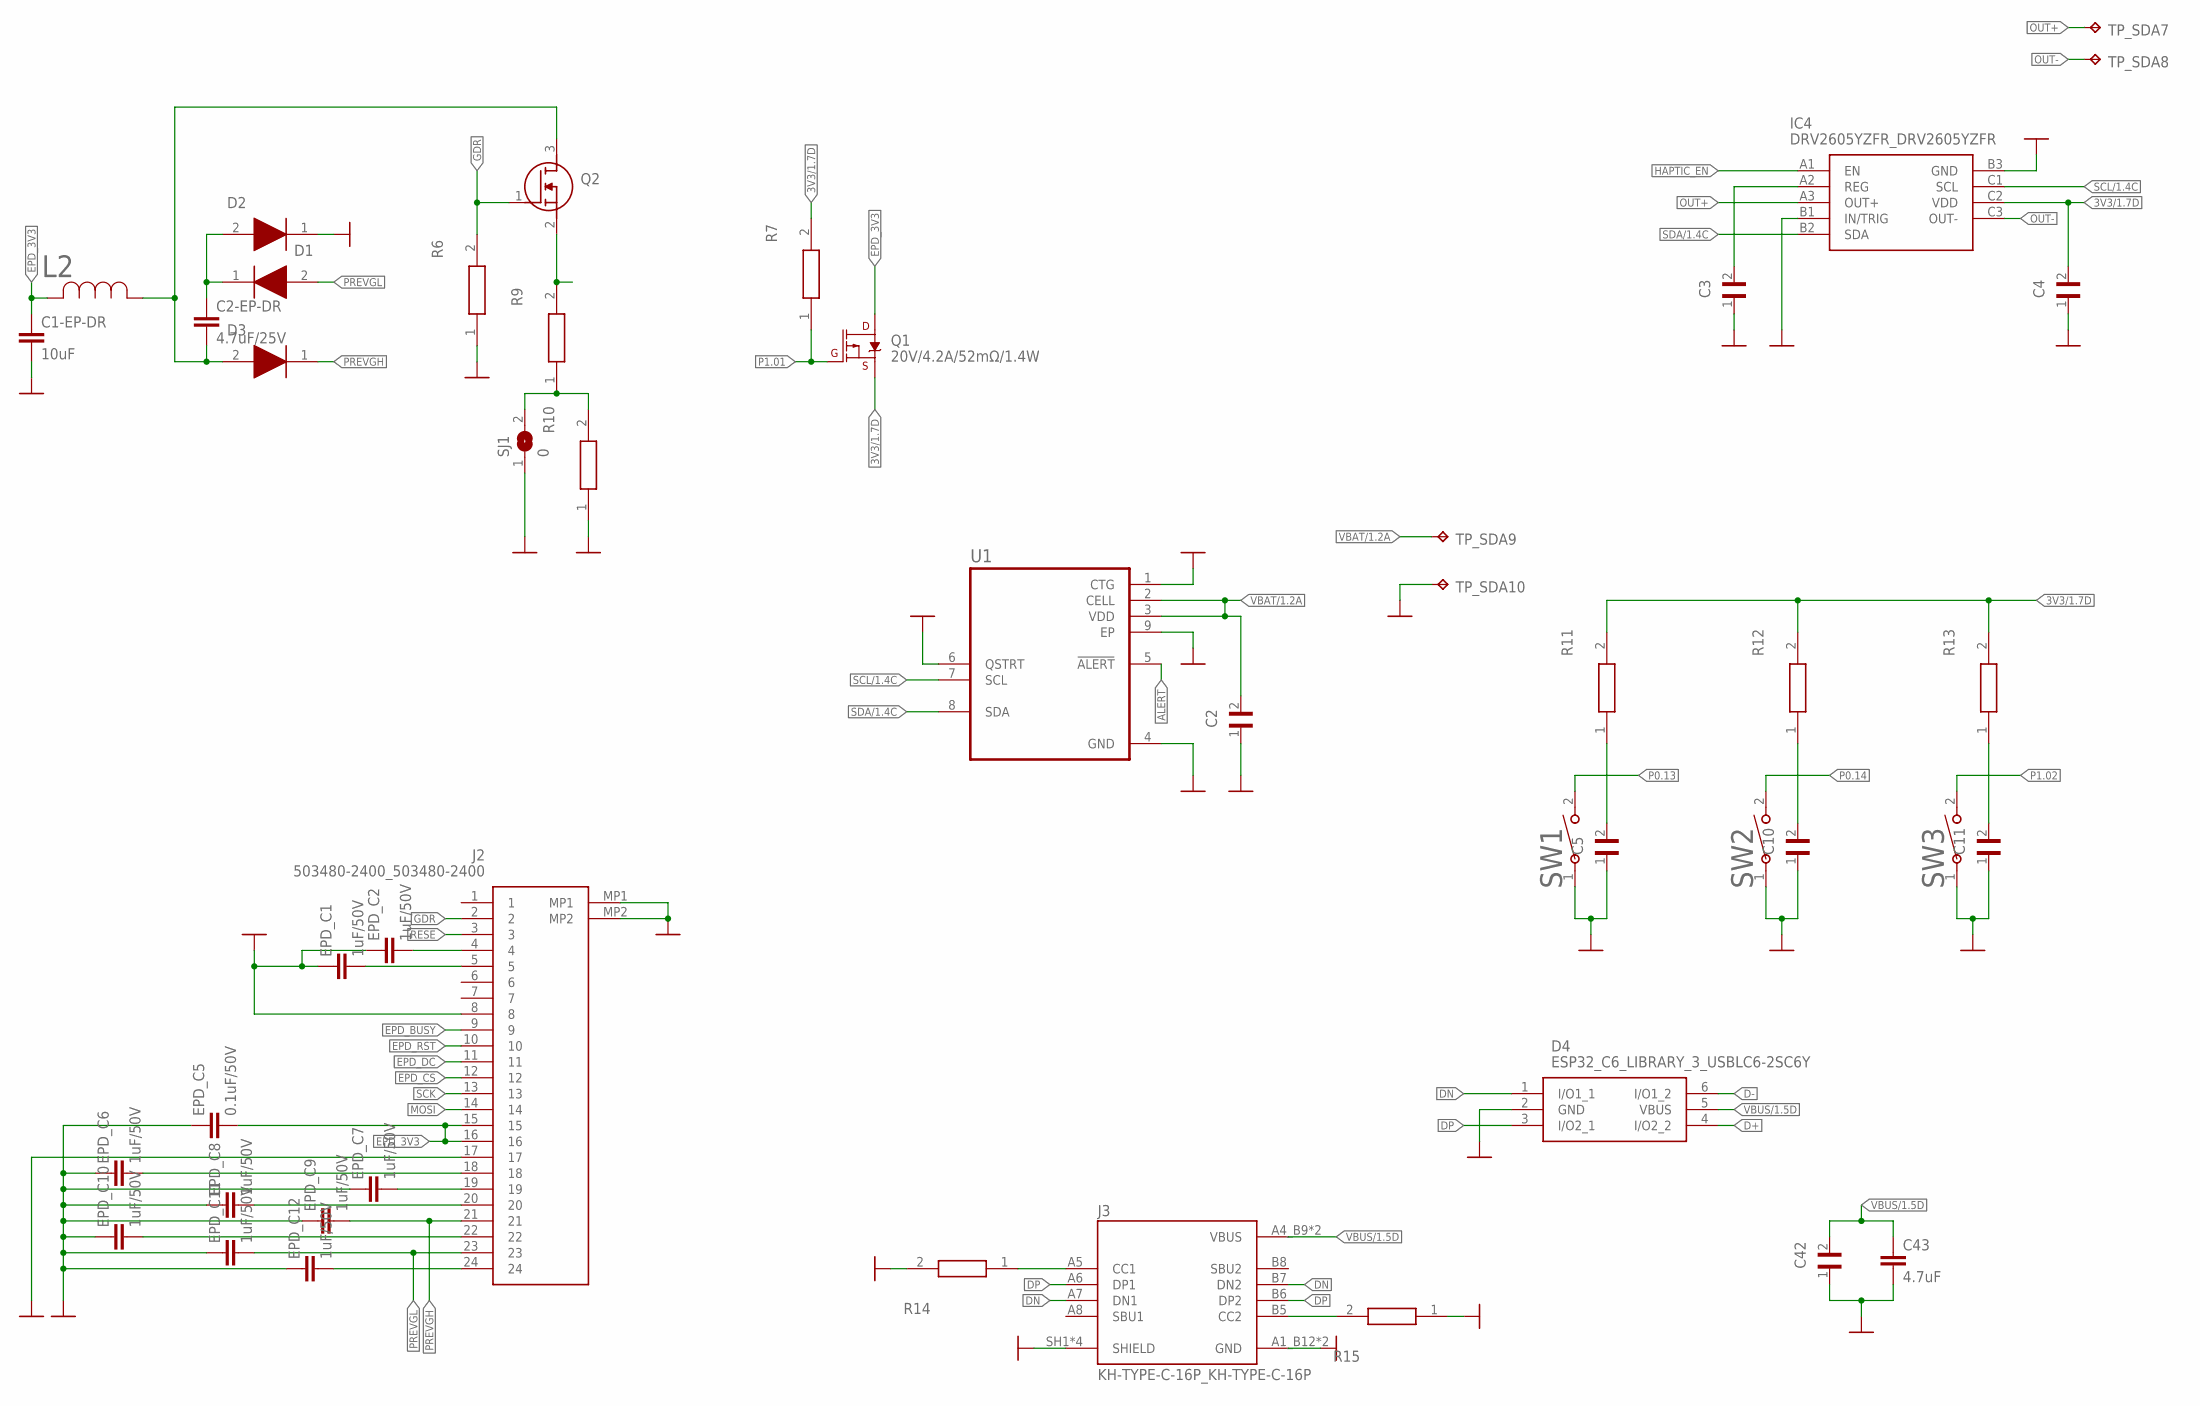
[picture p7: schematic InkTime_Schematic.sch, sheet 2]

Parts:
C1-EP-DR: 10uF; NORDIC_NRF_3_RESC0402_M
C2, C5, C10, C11, C42: GRM011R60J152KE01L_1_GRM011R60J152KE01L; GRM011R60J152KE01L_1_0201
C2-EP-DR: 4.7uF/25V; ESP32_C6_LIBRARY_1_ESP32_WROVER_EAGLE-LTSPICE_C0402
C3: 1uF; GRM011R60J152KE01L_1_0201
C4: 0.1uF; GRM011R60J152KE01L_1_0201
C43: 4.7uF; NORDIC_NRF_3_RESC0402_M
D1, D2, D3: ESP32_C6_LIBRARY_5_MBR0530; ESP32_C6_LIBRARY_5_SOD3716X135N
D4: ESP32_C6_LIBRARY_3_USBLC6-2SC6Y; ESP32_C6_LIBRARY_3_SOT95P280X145-6N
EPD_C1, EPD_C2, EPD_C6, EPD_C7, EPD_C8, EPD_C9, EPD_C10, EPD_C11, EPD_C12: 1uF/50V; NORDIC_NRF_3_RESC0402_M
EPD_C5: 0.1uF/50V; NORDIC_NRF_3_RESC0402_M
IC4: DRV2605YZFR_DRV2605YZFR; DRV2605YZFR_BGA9C50P3X3_144X144X62
J2: 503480-2400_503480-2400; 503480-2400_5034802400
J3: KH-TYPE-C-16P_KH-TYPE-C-16P; KH-TYPE-C-16P_KINGHELM_KH-TYPE-C-16P
L2: ESP32_C6_LIBRARY_2_744043680IND_4828-WE-TPC_WRE; ESP32_C6_LIBRARY_2_IND_4828-WE-TPC_WRE
Q1: 20V/4.2A/52mΩ/1.4W; ESP32_C6_LIBRARY_4_ESP32_C6_LIBRARY_4_ESP32_C6_LIBRARY_4_ES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
Q2: ESP32_C6_LIBRARY_6_SI1308EDL-T1-GE3; ESP32_C6_LIBRARY_6_SOT65P210X110-3N
R6, R7, R9, R10, R11, R12, R13, R14, R15: CPF0201D7K68C1_CPF0201D7K68C1; CPF0201D7K68C1_0201
SJ1: 0; ESP32_C6_LIBRARY_7_JUMPER_SJ
SW1, SW2, SW3: 2025-10-22_07-23-44_LIBRARY_EVP-AKE31ASW_EVP-AKE3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; 2025-10-22_07-23-44_LIBRARY_SW_EVP-AKE31A_PAN
TP_SDA7, TP_SDA8, TP_SDA9, TP_SDA10: HECTOR_WATCH_1_TPTP20R; HECTOR_WATCH_1_TP20R
U1: ESP32_C6_LIBRARY_MAX17048G+T10; ESP32_C6_LIBRARY_SON50P200X200X80-9N

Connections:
3V3/1.7D: C4.2, IC4.C2 (VDD), Q1.2 (S), R7.2, R11.2, R12.2, R13.2
ALERT: U1.5 (!ALERT); also elsewhere on the board
D+: D4.4 (I/O2_2); also elsewhere on the board
D-: D4.6 (I/O1_2); also elsewhere on the board
DN: D4.1 (I/O1_1), J3.A7 (DN1), J3.B7 (DN2)
DP: D4.3 (I/O2_1), J3.A6 (DP1), J3.B6 (DP2)
EPD_3V3: C1-EP-DR.1, EPD_C5.2, J2.15, J2.16, L2.2, Q1.3 (D)
EPD_BUSY: J2.9; also elsewhere on the board
EPD_CS: J2.12; also elsewhere on the board
EPD_DC: J2.11; also elsewhere on the board
EPD_RST: J2.10; also elsewhere on the board
GDR: J2.2, Q2.1 (G), R6.2
GND: C1-EP-DR.2, C2.1, C3.1, C4.1, C5.1, C10.1, C11.1, C42.1, C43.2, D2.1 (K), D4.2 (GND), EPD_C1.1, EPD_C2.1, EPD_C5.1, EPD_C6.1, EPD_C7.1, EPD_C8.1, EPD_C9.1, EPD_C10.1, EPD_C11.1, EPD_C12.1, IC4.B1 (IN/TRIG), IC4.B3 (GND), J2.8, J2.17, J2.MP1, J2.MP2, J3.A1_B12 (GND), J3.A12_B1 (GND), J3.SH1 (SHIELD), J3.SH2 (SHIELD), J3.SH3 (SHIELD), J3.SH4 (SHIELD), R6.1, R10.1, R14.2, R15.1, SJ1.1, SW1.1, SW2.1, SW3.1, TP_SDA10.TP, U1.1 (CTG), U1.4 (GND), U1.6 (QSTRT), U1.9 (EP); also elsewhere on the board
HAPTIC_EN: IC4.A1 (EN); also elsewhere on the board
MOSI: J2.14; also elsewhere on the board
unnamed: C2-EP-DR.1, D1.1 (K), D2.2 (A)
unnamed: Q2.2 (S), R9.2
unnamed: R9.1, R10.2, SJ1.2
unnamed: C2-EP-DR.2, D3.2 (A), L2.1, Q2.3 (D)
unnamed: EPD_C2.2, J2.4
unnamed: EPD_C1.2, J2.5
unnamed: J3.B5 (CC2), R15.2
unnamed: EPD_C7.2, J2.19
unnamed: C5.2, R11.1
unnamed: EPD_C12.2, J2.24
unnamed: EPD_C6.2, J2.18
unnamed: EPD_C8.2, J2.20
unnamed: C10.2, R12.1
unnamed: EPD_C10.2, J2.22
unnamed: C11.2, R13.1
unnamed: J3.A5 (CC1), R14.1
unnamed: C3.2, IC4.A2 (REG)
OUT+: IC4.A3 (OUT+), TP_SDA7.TP
OUT-: IC4.C3 (OUT-), TP_SDA8.TP
P0.13: SW1.2; also elsewhere on the board
P0.14: SW2.2; also elsewhere on the board
P1.01: Q1.1 (G), R7.1; also elsewhere on the board
P1.02: SW3.2; also elsewhere on the board
PREVGH: D3.1 (K), EPD_C9.2, J2.21
PREVGL: D1.2 (A), EPD_C11.2, J2.23
RESE: J2.3
SCK: J2.13; also elsewhere on the board
SCL/1.4C: IC4.C1 (SCL), U1.7 (SCL)
SDA/1.4C: IC4.B2 (SDA), U1.8 (SDA)
VBAT/1.2A: C2.2, TP_SDA9.TP, U1.2 (CELL), U1.3 (VDD)
VBUS/1.5D: C42.2, C43.1, D4.5 (VBUS), J3.A4_B9 (VBUS), J3.A9_B4 (VBUS)

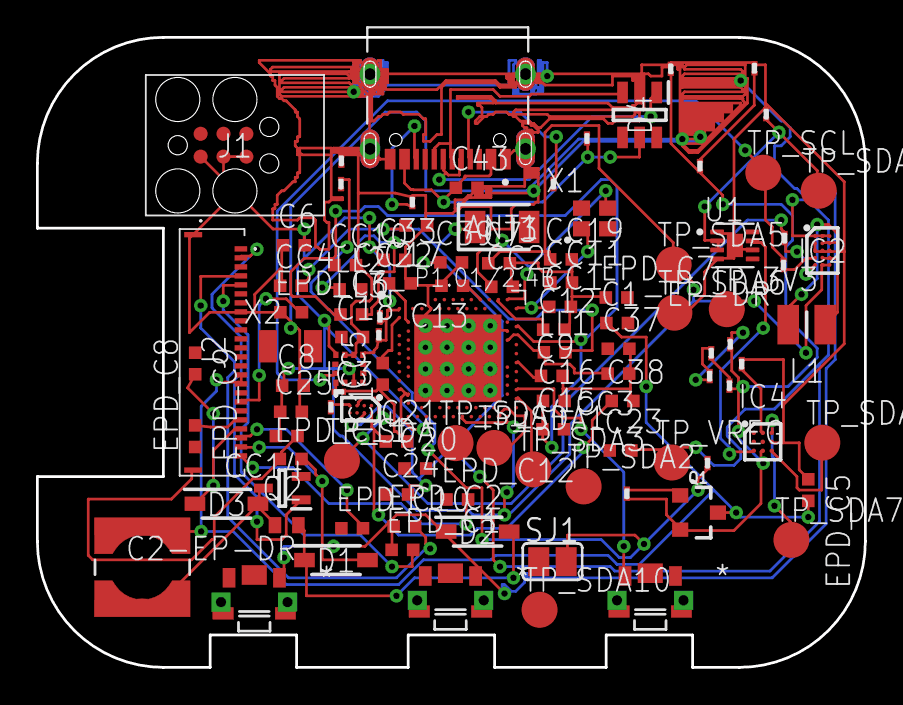
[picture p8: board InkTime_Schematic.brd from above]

Board: 2 copper layers, 46.0 x 35.0 mm, 105 parts (0 on the bottom side), 79 nets.

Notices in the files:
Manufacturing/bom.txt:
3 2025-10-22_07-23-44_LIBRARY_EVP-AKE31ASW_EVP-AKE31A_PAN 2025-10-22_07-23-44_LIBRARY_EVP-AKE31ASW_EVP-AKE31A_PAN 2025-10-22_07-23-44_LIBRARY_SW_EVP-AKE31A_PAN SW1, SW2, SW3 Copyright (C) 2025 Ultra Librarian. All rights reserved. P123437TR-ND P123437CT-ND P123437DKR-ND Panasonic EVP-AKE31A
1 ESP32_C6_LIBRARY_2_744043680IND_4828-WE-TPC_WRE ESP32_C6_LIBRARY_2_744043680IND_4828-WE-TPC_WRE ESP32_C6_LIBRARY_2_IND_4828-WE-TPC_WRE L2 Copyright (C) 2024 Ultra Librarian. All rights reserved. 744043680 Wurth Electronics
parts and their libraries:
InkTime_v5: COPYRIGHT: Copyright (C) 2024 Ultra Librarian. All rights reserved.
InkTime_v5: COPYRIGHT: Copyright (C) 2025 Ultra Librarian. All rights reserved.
